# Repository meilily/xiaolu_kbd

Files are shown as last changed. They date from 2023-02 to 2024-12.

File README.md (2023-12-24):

Xiaolu Keyboard
===============

この Xiaolu Keyboard は、Seeed Xiao を使用した小型の自作キーボードです。このキーボードは、テンキーやゲーム用のマクロキーボードなどとして使用できる、コンパクトで手のひらサイズのデバイスとして設計されています。キーボードには、4×4グリッドに配置された合計16個の小さなキーが使用されています。

このキーボードを作るには、基本的なハンダ付けの技術と工具、そしてSeeed Xiao用にファームウェアをビルドしてインストールする必要があります。必要なものがすべて揃ったら、ビルドガイドを参照してください。

キーボードの組み立てに成功したら、ArduinoやQMKなどのファームウェアを使って、独自のマクロやカスタム機能でキーボードをプログラムすることができます。Arduinoのサンプルファームウェアでは、例としてシンプルな4x4のテンキー機能を提供しています。

## 特徴

* 秋月C基板互換サイズでコンパクトで手のひらサイズ (51mm x 76mm)
* Switronic TS-AGGNH-G プッシュボタンの採用により小型ながらもキースイッチの押しやすさを両立
* MCU として Seeed XIAO を採用

## 手順書

* [パーツリスト](docs/bom.md)
* [ビルドガイド](docs/building_instruction.md)
* [拡張機能](docs/extensible_features.md)

## 外観図

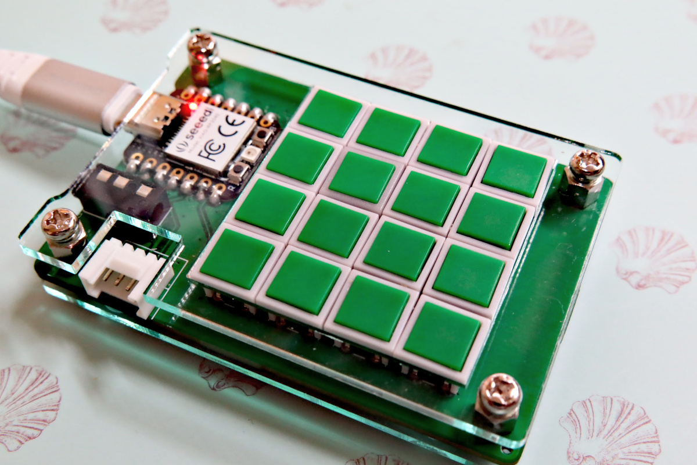
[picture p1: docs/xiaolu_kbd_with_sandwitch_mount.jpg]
組立例


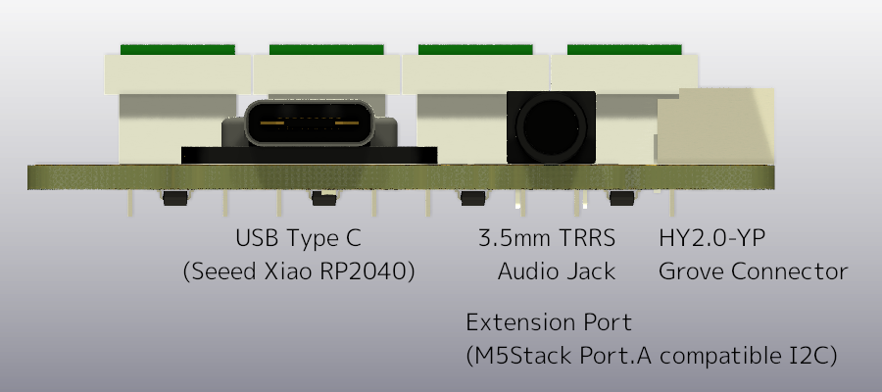
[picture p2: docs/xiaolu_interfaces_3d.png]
インタフェース(3D CG)


## License

licensed under the [CC-BY-SA-4.0](https://creativecommons.org/licenses/by-sa/4.0/) except for QMK.
QMK firmware source code is licensed under the [GPLv2](https://www.gnu.org/licenses/old-licenses/gpl-2.0.html)

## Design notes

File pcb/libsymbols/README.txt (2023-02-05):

Seeed_Studio_XIAO_Series.kicad_sym : https://github.com/Seeed-Studio/OPL_Kicad_Library/blob/master/Seeed%20Studio%20XIAO%20Series%20Library/Seeed_Studio_XIAO_Series.kicad_sym
keebio.lib : https://github.com/keebio/keebio-components/blob/master/keebio.lib

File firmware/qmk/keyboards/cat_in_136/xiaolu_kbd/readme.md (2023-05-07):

# Xiaolu KBD

cat\_in\_136/xiaolu\_kbd

*A short description of the keyboard/project*

* Keyboard Maintainer: [cat-in-136](https://github.com/cat-in-136)
* Hardware Supported: Xiaolu PCB, Seeed XIAO RP2040
* Hardware Availability: <https://github.com/cat-in-136/xiaolu_kbd>

Make example for this keyboard (after setting up your build environment):

    make cat_in_136/xiaolu_kbd:default

Flashing example for this keyboard:

    make cat_in_136/xiaolu_kbd:default:flash

See the [build environment setup](https://docs.qmk.fm/#/getting_started_build_tools) and the [make instructions](https://docs.qmk.fm/#/getting_started_make_guide) for more information. Brand new to QMK? Start with our [Complete Newbs Guide](https://docs.qmk.fm/#/newbs).

## Bootloader

Enter the bootloader in 3 ways:

* **Bootmagic reset**: Hold down the key at (0,0) in the matrix (usually the top left key or Escape) and plug in the keyboard
* **Physical reset button**: Briefly press the button on the back of the PCB - some may have pads you must short instead
* **Keycode in layout**: Press the key mapped to `QK_BOOT` if it is available

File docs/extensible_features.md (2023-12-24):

拡張機能
========

この Xiaolu Keyboard には、オプショナルなパーツとして Grove コネクタおよび TRRS ジャックをつけることができます。これらのインタフェースを介して他のユニットと接続し、ファームウェアを適切に実装することで、キーボードの機能を拡張することができます。

## 配線

Grove コネクタおよび TRRS ジャックは下記の通り接続されます。

|Seeed Xiao RP2040 Pin|Grove(M5Stack互換)|TRRS  |
|---|---|---|
|GND |1 (Black/GND) |Sleeve|
|5V |2 (Red/5V) |Tip |
|P6/SDA/D4 |3 (Yellow/SDA) |Ring2 |
|P7/SCL/D5 |4 (White/SCL) |Ring1 |



Grove コネクタと TRRS ジャックの電源供給は、どちらも 5V が供給されます。

I2C のプルアップは、3.3V に 4.7 kΩの抵抗を接続するのが標準です。
4.7 kΩの抵抗が PCB に実装されていますので、ハンダブリッジジャンパで有効にすることで、このプルアップすることができます。

I2C のプルアップ抵抗は、4.7 kΩが標準値ですが、必要に応じて変更してください。

## ファームウェア

### I2C -- Arduino/PlatformIO

RP2040 の標準の I2C 用途のピンを使っているので、ArduinoのWireライブラリの関数を使用して I2C デバイスにアクセスできます。
すなわち、 `Wire.begin()` 関数を使用して I2C バスを初期化し、 `Wire.write()` 関数を使用して I2C デバイスにデータを送信し、あるいは `Wire.read()` 関数を使用してデータを受信できます。

Wireライブラリの使い方の詳細については、[Arduino の Wireライブラリの公式ドキュメント](https://www.arduino.cc/reference/en/language/functions/communication/wire/)を参照してください。

```c++
#include <Wire.h>

void setup() {
  // ...
  Wire.begin();
  // ...
}

void loop() {
  Wire.requestFrom(device_address, 1);
  while (Wire.available()) {
    // Wire.read();
    // ...
  }
  // ...
}
```

### I2C -- QMK

QMKでI2Cを使用するには、以下の設定が必要です。

**rules.mk**: `QUANTUM_LIB_SRC` に `i2c_master.c` を追加します。

```make
QUANTUM_LIB_SRC += i2c_master.c
```

**halconf.h**: `HAL_USE_I2C` を `TRUE` に設定します。

```c++
#pragma once

#define HAL_USE_I2C TRUE

#include_next <halconf.h>
```

**mcuconf.h**: `RP_I2C_USE_I2C1` を `TRUE` に設定します。使わない `RP_I2C_USE_I2C0` は `FALSE` に設定します。

```c++
#pragma once

#include_next <mcuconf.h>

#undef RP_I2C_USE_I2C0
#undef RP_I2C_USE_I2C1
#define RP_I2C_USE_I2C0 FALSE
#define RP_I2C_USE_I2C1 TRUE
```

**config.h**: 以下の設定を追加します

* `I2C_DRIVER` は、I2Cドライバの種類として I2C1 を指定します。
* `I2C1_SCL_PIN` と `I2C1_SDA_PIN` は、I2C1のSCL/SDAピンを指定します。それぞれ `GP7`, `GP6` を指定します。

```c++
#pragma once

// I2C
#define I2C_DRIVER I2CD1
#define I2C1_SCL_PIN GP7
#define I2C1_SDA_PIN GP6
```

これらの設定を行った後、I2Cデバイスを操作できるようになります。

**keymap.c**: 例えば下記のようにして I2C デバイスを制御します。

* `keyboard_post_init_user()` で `i2c_init()` を呼ぶことで I2C ドライバを初期化します。
* `matrix_scan_user()` で I2C デバイスの処理を行います。
* [QMKのI2CドライバのAPI](https://github.com/qmk/qmk_firmware/blob/master/docs/i2c_driver.md#api-idapi)関数群を使って I2C デバイスと通信を行います。

```c++
static void handle_i2c_device(void) {
    static const uint16_t TIMEOUT = 100;

    uint8_t c[1] = {0};
    const i2c_status_t error = i2c_receive(I2C_DEVICE_ADDR << 1, c, sizeof(c), TIMEOUT);
    if (error != I2C_STATUS_SUCCESS) {
        return; // quit on failure
    }

    // ...
}

void matrix_scan_user(void) {
    // ...
    handle_i2c_device();
}

void keyboard_post_init_user(void) {
    // ...
    i2c_init();
}
```

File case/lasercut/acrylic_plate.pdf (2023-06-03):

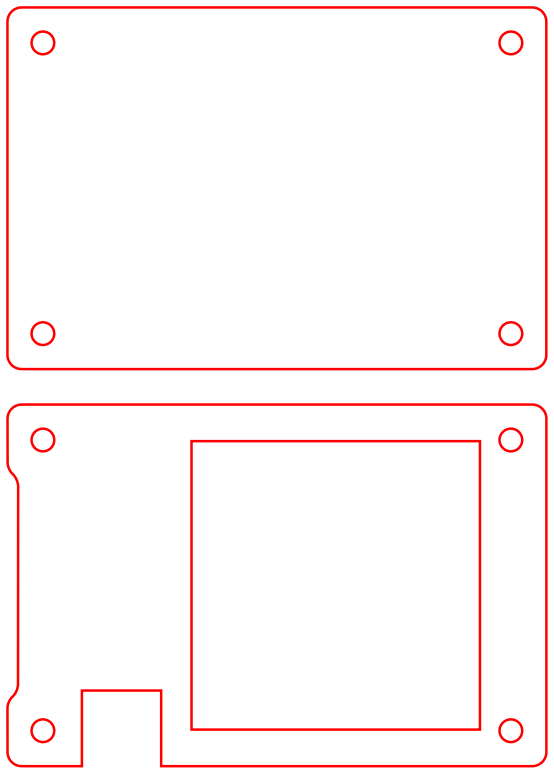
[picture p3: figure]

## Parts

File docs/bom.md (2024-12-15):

パーツリスト
============

## PCB

Xiaolu Keyboard PCBはKicad 6で設計され、51mm x 76mmの寸法を持つ2層設計になっています。PCBには、16個のダイオード（1N4148）と2個の4.7kΩ抵抗（4.7kΩ 0402 Resister）のSMT部品が含まれています。

.kicad_pcb、.kicad_schなどのPCB設計ファイルは、「pcb」フォルダーにあります。

このPCBは、一般的なPCBメーカーである[JLCPCB](https://jlcpcb.com/)で製造することを前提に設計されています。PCBをJLCPCB PCB+SMT製造サービスに発注するには、KiCadのプラグインで製造用のガーバーファイルなどのファブリケーションファイルを生成できる[JLCPCB fabrication toolkit](https://github.com/bennymeg/JLC-Plugin-for-KiCad)を利用することができます。このツールキットを使うと、JLCPCBに発注するのに必要なファブリケーションファイルであるgerber.zip、bom.csv、position.csvを生成できます。

SMT 部品表

|部品名 |数量|LCSC Part # |
|---|----|---|
|1N4148 Diode |16  |[C2128](https://www.lcsc.com/product-detail/Switching-Diode_Jiangsu-Changjing-Electronics-Technology-Co-Ltd-1N4148WS_C2128.html)|
|4.7kΩ 0402 Resistor|2 |[C25900](https://www.lcsc.com/product-detail/Chip-Resistor-Surface-Mount_UNI-ROYAL-Uniroyal-Elec-0402WGF4701TCE_C25900.html) |

## 電子部品

|部品名 |数量|秋月通販コード |備考 |
|---|----|---|---|
|Seeed XIAO RP2040 |1 |[117044](https://akizukidenshi.com/catalog/g/g117044/)|必須 |
|Switronic TS-AGGNH-G プッシュボタン |16  |[103654](https://akizukidenshi.com/catalog/g/g103654/)|必須 |
|USB Type C ケーブル |1 | |必須。適当なもので良い |
|GroveコネクタL型スルーホール |1 |[112634](https://akizukidenshi.com/catalog/g/g112634/)|Grove拡張用オプション部品|
|TRRS ジャック PJ-320A(または MJ-4PP-9)|1 |[106070](https://akizukidenshi.com/catalog/g/g106070/)|TRRS拡張用オプション部品 |

## ケース

ケースセットアップの例をいくつか記載します。

### 最も安価なケースセットアップ〜市販品の利用〜

Xiaolu Keyboard PCBは、ケースの組み立てを容易にするために、四隅にM3ホールが配置されています。このM3ホールは、秋月電子のC基板との互換となる配置と直径になっています。これにより、秋月電子C基板用のケースやアクリルパネルに、Xiaolu Keyboard を簡単に組み込むことができます。

以下は、最も安価なケースセットアップの一例です。より高さを低くするにはより短いスペーサーを使用してください。

|部品名 |数量|秋月通販コード |備考 |
|---|----|---|---|
|C基板用アクリルパネル |1 |[109853](https://akizukidenshi.com/catalog/g/g109853/)| |
|3mmプラネジ(7mm)+六角スペーサー(14mm)セット|1 |[101861](https://akizukidenshi.com/catalog/g/g101861/)|8 x M3プラネジと4 x M3スペーサーのセット|

### サンドイッチマウントケース

カードケース（名刺ケース）に入るよう設計されたサンドイッチマウントケースです。

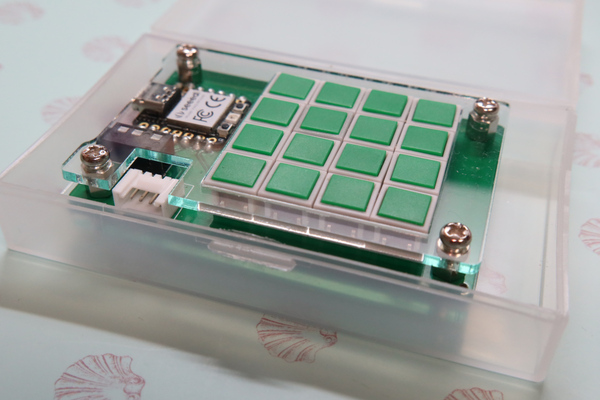
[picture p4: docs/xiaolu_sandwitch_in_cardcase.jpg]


アクリル板のデザインは [case/lasercut/acrylic_plate.pdf](../case/lasercut/acrylic_plate.pdf) にあります。
お手持ちのレーザー加工機もしくはレーザー加工サービスの入稿条件に従って編集しボトムプレートとトッププレートを製造してください。

|部品名 |数量|通販 |備考 |
|---|----|---|---|
|ボトムプレート (76mm x 51mm x 2mm)|1 | |※レーザー加工によって製造 |
|トッププレート (76mm x 51mm x 2mm)|1 | |※レーザー加工によって製造 |
|なべ小ねじ M3 x 4mm |4 |[千石電商: EEHD-6DKV](https://www.sengoku.co.jp/mod/sgk_cart/detail.php?code=EEHD-6DKV)| |
|なべ小ねじ M3 x 8mm |4 |[千石電商: EEHD-6DKY](https://www.sengoku.co.jp/mod/sgk_cart/detail.php?code=EEHD-6DKY)| |
|六角ナット M3 x 2.4mm |4 |[千石電商: EEHD-6EBP](https://www.sengoku.co.jp/mod/sgk_cart/detail.php?code=EEHD-6EBP)|スペーサの代わりに使用。JIS B1181 規格の六角ナット|
|六角スペーサ 両メネジ M3 x 5mm |4 |[千石電商: EEHD-0DLK](https://www.sengoku.co.jp/mod/sgk_cart/detail.php?code=EEHD-0DLK)| |

## 工具

Xiaolu Keyboard PCBはハンダ付けが必要なため、ハンダ付けやその他の電子工作のための一般的な工具が必要です。

* ハンダごて - 温度調節機能付きのものでも、ベーシックなものでもよいのですが、温度調節機能付きのものを強くお勧めします。
* ハンダ - この組み立てには、はんだが必要です。
* ドライバーセット - ケースの組み立てには、ドライバーセットが必要です。

工具を扱うときは、常に適切な安全対策に従ってください。

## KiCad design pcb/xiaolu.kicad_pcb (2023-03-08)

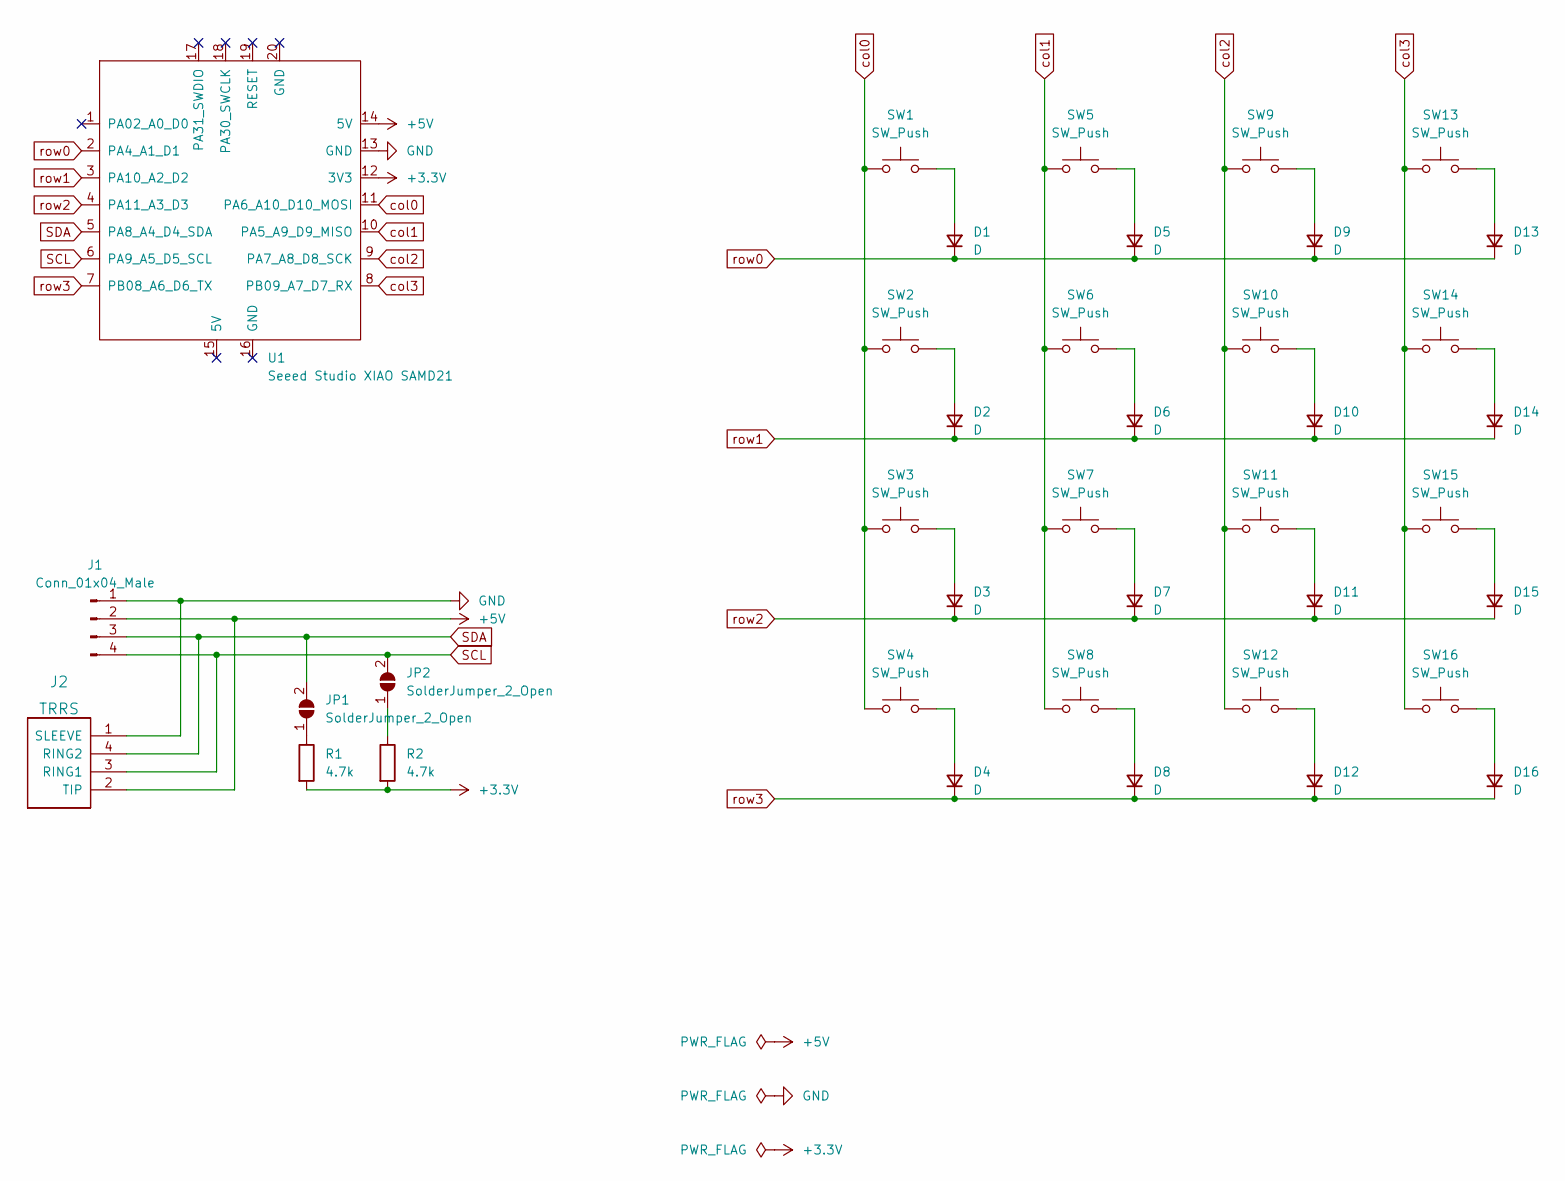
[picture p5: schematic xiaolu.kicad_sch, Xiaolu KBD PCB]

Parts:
D1, D2, D3, D4, D5, D6, D7, D8, D9, D10, D11, D12, D13, D14, D15, D16: D; D_SOD-323; LCSC Part # C2128
J1: Conn_01x04_Male; NS-Tech_Grove_1x04_P2mm_Hybrid
J2: TRRS; TRRS-PJ-320A
JP1, JP2: SolderJumper_2_Open; SolderJumper-2_P1.3mm_Open_RoundedPad1.0x1.5mm
R1, R2: 4.7k; R_0402_1005Metric; LCSC Part # C25900
SW1, SW2, SW3, SW4, SW5, SW6, SW7, SW8, SW9, SW10, SW11, SW12, SW13, SW14, SW15, SW16: SW_Push; SW_PUSH_Switronic_TS-AXXXH
U1: Seeed Studio XIAO SAMD21; XIAO-Generic-Hybrid-14P-2.54-21X17.8MM

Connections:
+3.3V: R1.2, R2.2, U1.12 (3V3)
+5V: J1.2, J2.2 (TIP), U1.14 (5V)
GND: J1.1, J2.1 (SLEEVE), U1.13 (GND)
unnamed: D1.2 (A), SW1.2
unnamed: D2.2 (A), SW2.2
unnamed: D3.2 (A), SW3.2
unnamed: D4.2 (A), SW4.2
unnamed: D5.2 (A), SW5.2
unnamed: D6.2 (A), SW6.2
unnamed: D7.2 (A), SW7.2
unnamed: D8.2 (A), SW8.2
unnamed: D9.2 (A), SW9.2
unnamed: D10.2 (A), SW10.2
unnamed: D11.2 (A), SW11.2
unnamed: D12.2 (A), SW12.2
unnamed: D13.2 (A), SW13.2
unnamed: D14.2 (A), SW14.2
unnamed: D15.2 (A), SW15.2
unnamed: D16.2 (A), SW16.2
unnamed: JP1.1 (A), R1.1
unnamed: JP2.1 (A), R2.1
SCL: J1.4, J2.3 (RING1), JP2.2 (B), U1.6 (PA9_A5_D5_SCL)
SDA: J1.3, J2.4 (RING2), JP1.2 (B), U1.5 (PA8_A4_D4_SDA)
col0: SW1.1, SW2.1, SW3.1, SW4.1, U1.11 (PA6_A10_D10_MOSI)
col1: SW5.1, SW6.1, SW7.1, SW8.1, U1.10 (PA5_A9_D9_MISO)
col2: SW9.1, SW10.1, SW11.1, SW12.1, U1.9 (PA7_A8_D8_SCK)
col3: SW13.1, SW14.1, SW15.1, SW16.1, U1.8 (PB09_A7_D7_RX)
row0: D1.1 (K), D5.1 (K), D9.1 (K), D13.1 (K), U1.2 (PA4_A1_D1)
row1: D2.1 (K), D6.1 (K), D10.1 (K), D14.1 (K), U1.3 (PA10_A2_D2)
row2: D3.1 (K), D7.1 (K), D11.1 (K), D15.1 (K), U1.4 (PA11_A3_D3)
row3: D4.1 (K), D8.1 (K), D12.1 (K), D16.1 (K), U1.7 (PB08_A6_D6_TX)

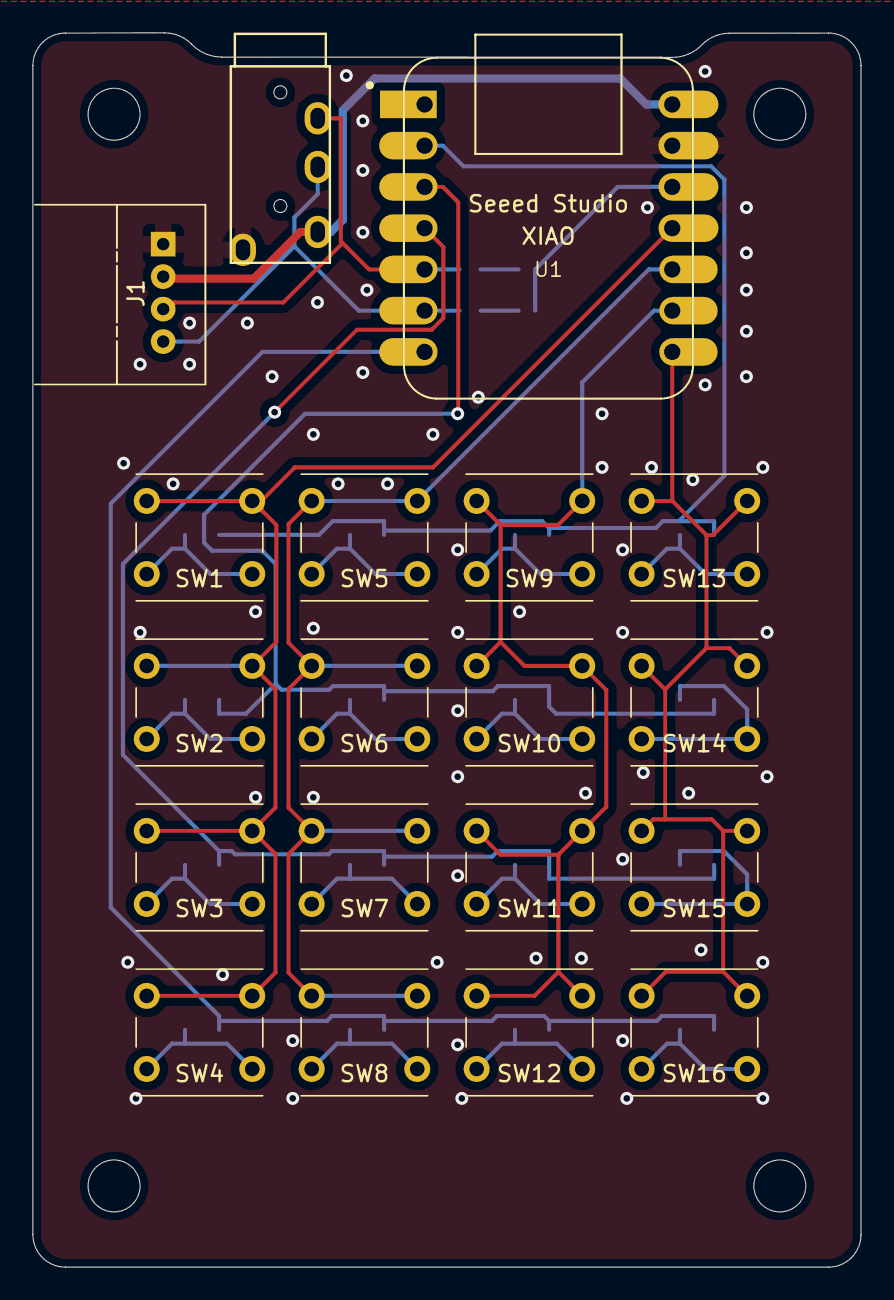
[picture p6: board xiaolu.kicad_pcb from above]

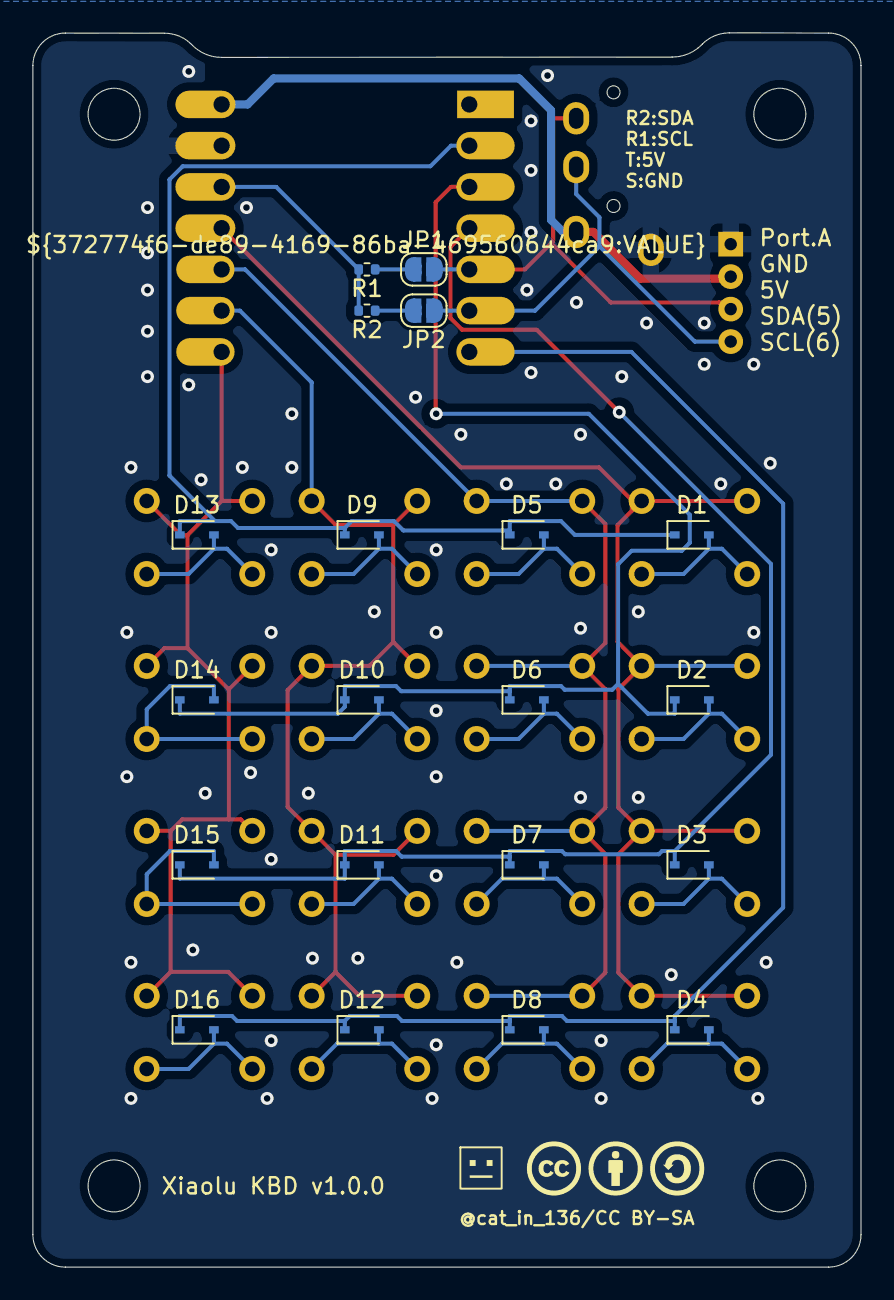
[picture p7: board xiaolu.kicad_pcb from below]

Board: 2 copper layers, 51.0 x 76.0 mm, 39 parts (20 on the bottom side), 31 nets.

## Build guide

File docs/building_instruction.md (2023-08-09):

ビルドガイド
============

## PCB 実装

### ステップ 0

ダイオードや抵抗がPCB+SMT製造サービスによって既に実装されている場合は、このステップをスキップしてください。

* 16 x 1N4148 Diodes (D1-D16)
* 2 x 4.7kΩ 0402 Resistor (R1, R2)

これらのダイオードは方向性があります。カソードが左、アノードが右です。

### ステップ 1

* Seeed Xiao RP2040 (U1)

PCB上にSeeed Xiaoボードを置き、Seeed Xiaoの端面スルーホールととPCB上の対応するパッドが以下の3D CGのように一致するようにします。

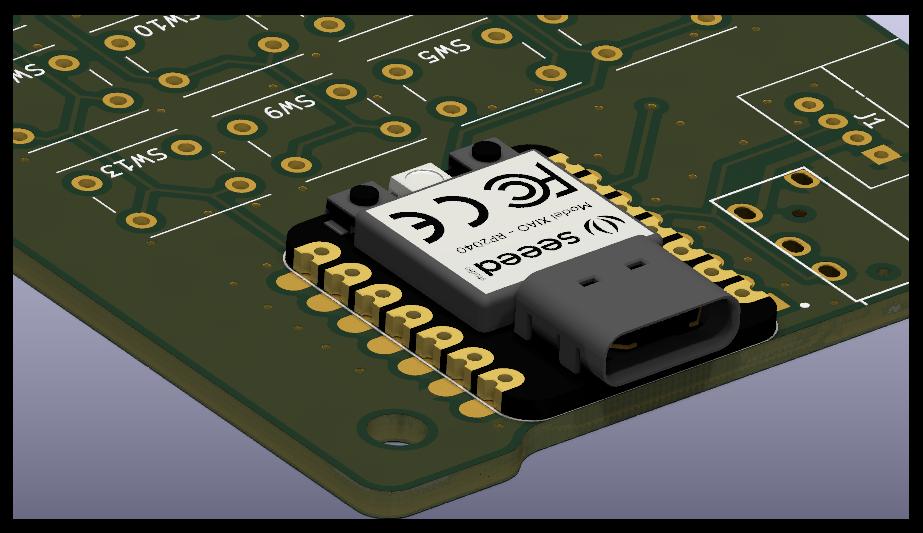
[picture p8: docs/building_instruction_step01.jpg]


それぞれの端面スルーホールをとパッドをはんだ付けします。

補足：また、プリント基板にはスルーホールが設けられています。これは位置合わせのために使うこともできますし、強度を増すなどの理由があればスルーホールをハンダ付けすることも可能です。

### ステップ 2

* 1 x TRRS ジャック PJ-320A(または MJ-4PP-9) (TRRS)

TRRS拡張用オプション部品です。不要な場合はこのステップをスキップしてください。

TRRSジャックをPCBに挿入してテープで固定します。フットプリントがぴったり合うように作られているので、きちんと押し込んでください。PCBを裏返します。ピンをはんだ付けします。テープを剥がします。

### ステップ 3

* 1 x GroveコネクタL型スルーホール (J1)

Grove拡張用オプション部品です。不要な場合はこのステップをスキップしてください。

GroveコネクタをPCBに挿入してテープで固定します。PCBを裏返します。ピンをはんだ付けします。テープを剥がします。

### ステップ 4

* 16 x Switronic TS-AGGNH-G プッシュボタン (SW1-16)

プッシュボタンをPCBに挿入してテープで固定します。

スルーホールにうまく入らない場合は、プッシュボタンの足をペンチなどでまっすぐにして入りやすくしてください。
下図の左がペンチでまっすぐにした後の足です。

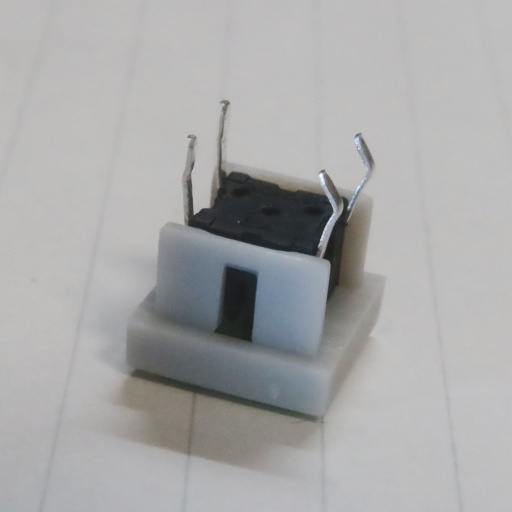
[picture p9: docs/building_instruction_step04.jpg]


PCBを裏返します。ピンをはんだ付けします。テープを剥がします。

## ケース

### 最も安価なケースセットアップ〜市販品の利用〜

下図のようにして、アクリルパネルをスペーサーとプラネジで固定します。

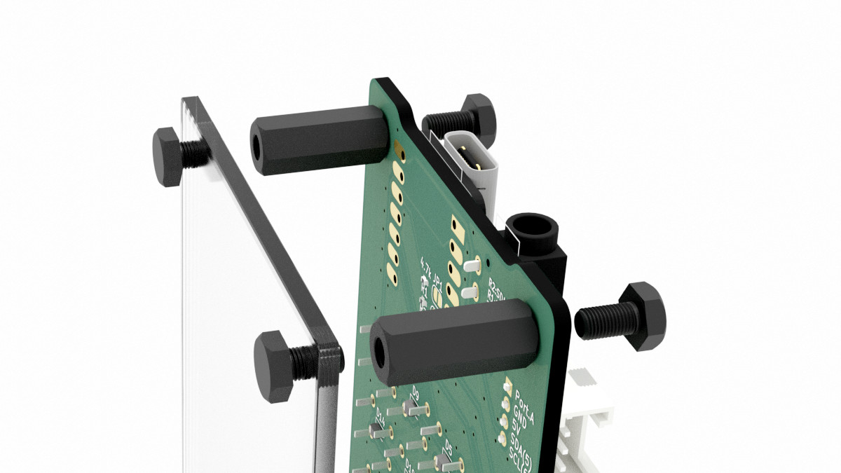
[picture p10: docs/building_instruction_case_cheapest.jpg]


### サンドイッチマウントケース

PCB背面に出ているプッシュボタン Switronic TS-AGGNH-G プッシュボタン (SW1-16) および GroveコネクタL型スルーホール (J1) の足が 2mm 以上出ている場合はニッパーなどで切りそろえます。

なべ小ねじ M3 x 8mm → ボトムプレート → 六角ナット M3 x 2.4mm → PCB → 六角スペーサ → トッププレート → なべ小ねじ M3 x 4mm の順番に重ねます。
両端のねじをドライバーなどでしっかりと締めて固定します。

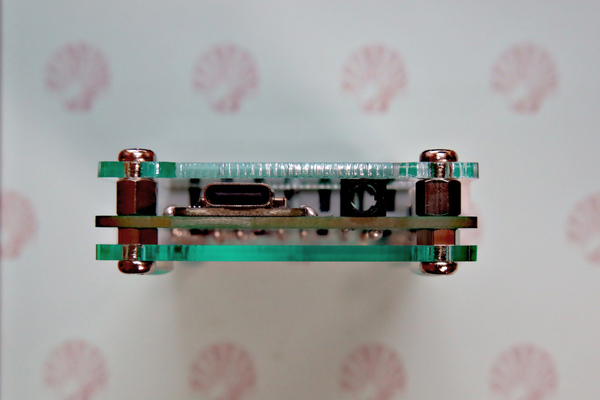
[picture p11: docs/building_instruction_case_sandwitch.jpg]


TRRSジャックを付けている場合にはTRRSジャックもトッププレートが支える実装となります。

## ファームウェア

サンプルファームウエアは Platform IO (Arduino) と QMK を用意しています。

### Platform IO/Arduino

サンプルファームウェアの Platform IO プロジェクトは [/firmware/platformio_arduino](../firmware/platformio_arduino) にあります。

必要に応じてプログラムを追加・編集してください。
[サンプルファームウエアのコード](../firmware/platformio_arduino/src/main.c) はシンプルなテンキーで、
さらにGroveコネクタに[M5stack CardKB Unit](https://docs.m5stack.com/en/unit/cardkb_1.1)をつないだときCardKB Unitの入力をキーボード入力に変換する処理が含まれます。

以下に Windows + Visual Studio Code 環境でのファームウェアのビルド・アップロードの方法を記載します。

1. <https://zadig.akeo.ie/> から Zadig をダウンロードします
2. Zadig を起動します
3. PC の USB に Xiaolu KBD をつなぎます
4. Seeed Xiao RP2040 の BOOTボタンを押した状態でリセットボタンを押します。すると、USBマスストレージモード(RPI-RP2)でつながります
5. すると Zadig のウィンドウで RP2 Boot (Interface X) が選択されます。選択されない場合はセレクトボックスから選択します
6. インストール先のドライバとして WinUSB を選択して、 Install Driver ボタンをクリックします
7. しばらくすると The driver was installed successfuly というダイアログが表示されドライバがインストールされます。これで Zadig のウィンドウを閉じます
8. <https://github.com/git-for-windows/git/releases/latest> から Git for Windows をダウンロード・インストールします
9. 後述の手順16でファイルパスが長いことに起因するエラーを防ぐため、以下の手順でロングパス対応します
    1. レジストリエディタを開きます
    2. `コンピューター\HKEY_LOCAL_MACHINE\SYSTEM\CurrentControlSet\Control\FileSystem` に移動します
    3. `LongPathsEnabled` というDWORDの値があることを確認します。ない場合は作成します
    4. `LongPathsEnabled` の値を `1` に設定します
    5. コマンドプロンプトを開き、`git config --system core.longpaths true` と入力して実行します
    6. Windows を再起動します
10. <https://code.visualstudio.com/> から Visual Studio Code をダウンロード・インストールします
11. Visual Studio Code を起動して [PlatformIO IDE](https://marketplace.visualstudio.com/items?itemName=platformio.platformio-ide) 拡張をインストールします。（ VS Code Quick Open (Ctrl+P) で表示されるテキストボックスに `ext install platformio.platformio-ide` を入力して Enter でインストール出来ます ）
12. PlatformIO IDE has been installed successfully installed! Please reload windows と表示されるので Reload Now と書かれたボタンをクリックします
13. <https://github.com/cat-in-136/xiaolu_kbd> を Git で適当なフォルダにクローンするか、 <https://codeload.github.com/cat-in-136/xiaolu_kbd/zip/refs/heads/main> からダウンロードして適当なフォルダに展開します
14. Visual Studio Code の Platformio をクリックして、Pick a folder をクリックし、前項で展開したフォルダの中の [firmware\\platformio_arduino](../firmware/platformio_arduino) 相当のフォルダを選択します
15. "Do you trust the authors of the files in this folder?" というダイアログが出たら "Yes, I trust the authors" と書かれたボタンをクリックします
16. すると依存ライブラリのダウンロードなど (PlatformIO: Configuring project) がされますのでしばらく待ちます
17. Visual Studio Code の下の [PlatformIO Toolbar](https://docs.platformio.org/en/latest/integration/ide/vscode.html#ide-vscode-toolbar) から → Upload をクリックします
    * 手順 17 でファームウェアのアップロードに失敗するときは、USB がきちんとささっていない他に、 WinUSB がインストールされていない場合があります。

### QMK

[/firmware/qmk/keyboards/cat_in_136/xiaolu_kbd](../firmware/qmk/keyboards/cat_in_136/xiaolu_kbd) を `keyboards/cat_in_136/xiaolu_kbd` にコピーして QMK をビルド・アップロードします。

必要に応じてキーマップを追加・編集してください。
デフォルトキーマップはシンプルなテンキーになっています。

以下に Windows + QMK MSYS 環境でのファームウェアのビルド・アップロードの方法を記載します。

1. <https://msys.qmk.fm/> から QMK MSYS をダウンロード・インストールします
2. QMK MSYS を起動します。
3. コンソール画面で下記を実行します。
   ```console
   $ qmk setup
   ```
4. <https://github.com/cat-in-136/xiaolu_kbd> を Git で適当なフォルダにクローンするか、 <https://codeload.github.com/cat-in-136/xiaolu_kbd/zip/refs/heads/main> からダウンロードして適当なフォルダに展開します
5. 前項で展開したフォルダから `firmware/qmk` を `qmk_firmware/keyboards/cat_in_136/xiaolu_kbd` にコピーします。
   ```console
   $ mkdir qmk_firmware/keyboards/cat_in_136
   $ cp -r path/to/xiaolu_kbd/firmware/qmk/keyboards/cat_in_136/xiaolu_kbd qmk_firmware/keyboards/cat_in_136/xiaolu_kbd
   ```
6. qmk をコンパイルします。
   ```console
   $ qmk compile -kb cat_in_136/xiaolu_kbd -km default
   $ qmk flash -kb cat_in_136/xiaolu_kbd -km default
   ```
7. qmk をアップロードします。
   ```console
   $ qmk flash -kb cat_in_136/xiaolu_kbd -km default
   ```
8. 途中で Waiting for drive to deploy... と表示されるので、Seeed Xiao RP2040 の BOOTボタンを押した状態でリセットボタンを押します。するとファームウエアの書き込みが完了します。
9. Xiaolu KBD がキーボードとして認識されるまでしばらく待ちます。

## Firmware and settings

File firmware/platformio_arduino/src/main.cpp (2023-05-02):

#include <Adafruit_Keypad.h>
#include <Adafruit_NeoPixel.h>
#include <Arduino.h>
#include <Keyboard.h>
#include <Wire.h>

/// Row count of the key matrix
static const byte KEY_ROWS = 4;

/// Column count of the key matrix
static const byte KEY_COLS = 4;

/// Row pins (OUT) of the key matrix
static const byte KEY_ROWPINS[KEY_ROWS] = {
    // D1, D2, D3, D6
    27, 28, 29, 0};

/// Column pins (IN) of the key matrix
static const byte KEY_COLPINS[KEY_COLS] = {
    // D10, D9, D8, D7
    3, 4, 2, 1};

/// Definition of the symbol for each key
///
/// @attention
/// Xiaolu is different from the input/output pin layout assumed by
/// Adafruit_Keypad, so symbol is specified in an inverted matrix.
static const char KEY_SYMBOL[KEY_COLS][KEY_ROWS] = {{'7', '4', '1', '0'},
                                                    {'8', '5', '2', '.'},
                                                    {'9', '6', '3', '\n'},
                                                    {'/', '*', '-', '+'}};

/// Key matrix
Adafruit_Keypad keymatrix(makeKeymap(KEY_SYMBOL),
                          const_cast<byte *>(KEY_COLPINS),
                          const_cast<byte *>(KEY_ROWPINS), KEY_COLS, KEY_ROWS);

/// I2C address of M5Stack CardKB
static const uint8_t CARKB_ADDR = 0x5F;

/// Symbol Key Mapping for M5Stack CardKB
static const uint8_t CARKB_KEYMAP[][3] = {
    {0x08, KEY_BACKSPACE, 0},
    {0x09, KEY_TAB, 0},
    {0x0D, KEY_RETURN, 0},
    {0x1B, KEY_ESC, 0},
    {0xb5, KEY_UP_ARROW, 0},
    {0xb6, KEY_DOWN_ARROW, 0},
    {0xb4, KEY_LEFT_ARROW, 0},
    {0xb7, KEY_RIGHT_ARROW, 0},
    // Shift + Key combination
    {0x7f, KEY_DELETE, 0}, // Shift + Backspace
    // Fn + Key combination
    {0x81, KEY_F1, 0},           // Fn + 1
    {0x82, KEY_F2, 0},           // Fn + 2
    {0x83, KEY_F3, 0},           // Fn + 3
    {0x84, KEY_F4, 0},           // Fn + 4
    {0x85, KEY_F5, 0},           // Fn + 5
    {0x86, KEY_F6, 0},           // Fn + 6
    {0x87, KEY_F7, 0},           // Fn + 7
    {0x88, KEY_F8, 0},           // Fn + 8
    {0x89, KEY_F9, 0},           // Fn + 9
    {0x8a, KEY_F10, 0},          // Fn + 0
    {0x8b, KEY_F11, 0},          // Fn + Backspace
    {0x99, KEY_PAGE_UP, 0},      // Fn + Up
    {0xa4, KEY_PAGE_DOWN, 0},    // Fn + Down
    {0x98, KEY_HOME, 0},         // Fn + Left
    {0xa5, KEY_END, 0},          // Fn + Right
    {0x96, KEY_PRINT_SCREEN, 0}, // Fn + P
    {0xa6, 'z', KEY_LEFT_CTRL},  // Fn + Z
    {0xa7, 'x', KEY_LEFT_CTRL},  // Fn + X
    {0xa8, 'c', KEY_LEFT_CTRL},  // Fn + C
    {0xa9, 'v', KEY_LEFT_CTRL},  // Fn + V
    {0xaa, KEY_PAUSE, 0},        // Fn + B
    {0xab, KEY_NUM_LOCK, 0},     // Fn + N
    {0xac, KEY_MENU, 0},         // Fn + M
    {0xaf, ' ', KEY_LEFT_CTRL},  // Fn + SPACE
};

/// LED length of the NeoPixel LED
static const uint16_t NEO_NUMPIXELS = 1;

/// Power pin of NeoPixel LED
static const pin_size_t NEO_PWR = 11; // GPIO11

/// Pixel data pin of NeoPixel LED
static const pin_size_t NEO_PIX = 12; // GPIO12

/// NeoPixel LED
Adafruit_NeoPixel pixels(NEO_NUMPIXELS, NEO_PIX, NEO_GRB + NEO_KHZ800);

/// Arduino setup entry point (Core 0)
void setup() {
  pixels.begin();
  pinMode(NEO_PWR, OUTPUT);
  digitalWrite(NEO_PWR, HIGH);

  pixels.setBrightness(25);
  pixels.setPixelColor(0, pixels.Color(255, 255, 255));
  pixels.show();

  Serial.begin(115200);
  // while (!Serial) { delay(1); }
  delay(100);
  Serial.println("Boot Xiaolu KBD Arduino FW ...");

  keymatrix.begin();

  Keyboard.begin();

  Wire.begin();

  delay(2000);

  pixels.setPixelColor(0, pixels.Color(0, 0, 0));
  pixels.show();

  Serial.println("Ready.");
}

/// Arduino loop function (Core 0)
void loop() {
  uint8_t key_count = 0;

  keymatrix.tick();

  while (keymatrix.available()) {
    const keypadEvent e = keymatrix.read();
    const char key = (char)e.bit.KEY;

    Serial.print((key == '\n') ? "ENTER" : String(key));
    if (e.bit.EVENT == KEY_JUST_PRESSED) {
      Serial.println(" pressed.");
    } else if (e.bit.EVENT == KEY_JUST_RELEASED) {
      Serial.println(" released");
    }
    Serial.flush();

    uint8_t key_code = 0;
    if (key == '0') {
      key_code = KEY_KP_0;
    } else if (isDigit(key)) {
      key_code = KEY_KP_1 + (key - KEY_KP_1);
    } else if (key == '.') {
      key_code = KEY_KP_DOT;
    } else if (key == '/') {
      key_code = KEY_KP_SLASH;
    } else if (key == '*') {
      key_code = KEY_KP_ASTERISK;
    } else if (key == '-') {
      key_code = KEY_KP_MINUS;
    } else if (key == '+') {
      key_code = KEY_KP_PLUS;
    } else if (key == '\n') {
      key_code = KEY_KP_ENTER;
    }

    if ((key_code != 0) && (e.bit.EVENT == KEY_JUST_PRESSED)) {
      Keyboard.press(key_code);
    } else if ((key_code != 0) && (e.bit.EVENT == KEY_JUST_RELEASED)) {
      Keyboard.release(key_code);
    }
  }

  Wire.requestFrom(CARKB_ADDR, 1);
  while (Wire.available()) {
    const char c = Wire.read();
    if (c != 0) {
      if (isPrintable(c)) {
        Serial.printf("%02x \"%c\" received from CardKB\n", c, c);
        Keyboard.write(c);
      } else {
        Serial.printf("%02x received from CardKB\n", c);

        uint8_t key_code = 0;
        uint8_t modifier_key_code = 0;
        for (const auto keymap : CARKB_KEYMAP) {
          if (c == keymap[0]) {
            key_code = keymap[1];
            modifier_key_code = keymap[2];
            break;
          }
        }

        if (key_code != 0) {
          if (modifier_key_code != 0) {
            Keyboard.press(modifier_key_code);
            delay(10);
          }
          Keyboard.press(key_code);
          delay(10);
          Keyboard.releaseAll();
        }
      }
    }
  }

  delay(10);
}

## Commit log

2023-02-02 introduce pcb directory (with empty pcb design)
    [xiaolu.kicad_pcb, xiaolu.kicad_sch]
2023-02-05 draft schematic and board design
    [Grove_Connector.scad, PJ-320A.step, TS-AGGNH-G.scad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]
2023-02-05 fix TRRS symbol
    [xiaolu.kicad_pcb, xiaolu.kicad_sch]
2023-02-08 replace XIAO footprint with XIAO-Generic-Hybrid-14P-2.54-21X17.8MM
    [xiaolu.kicad_pcb, xiaolu.kicad_sch]
2023-02-17 add notch for XIAO-usb and TRRS-jack to the PCB board edge
    [xiaolu.kicad_pcb]
2023-02-18 put each silk label on its internal
    [xiaolu.kicad_pcb]
2023-02-18 add slikscreen logos and label
    [xiaolu.kicad_pcb]
2023-02-18 fix Grove connector
    [xiaolu.kicad_pcb, xiaolu.kicad_sch]
2023-02-18 add I2C pin layout label
    [xiaolu.kicad_pcb]
2023-02-19 use NS-Tech_Grove_1x04_P2mm_Hybrid.kicad_mod for grove connector footprint and fix the Grove connector position
    [xiaolu.kicad_pcb, xiaolu.kicad_sch]
2023-02-19 fix SDA/SCL pin numbers of I2C pin layout label
    [xiaolu.kicad_pcb]
2023-02-21 Assign "LCSC Part #" of diodes (D1....D16) to C2128 (1N4148WS)
    [xiaolu.kicad_pcb, xiaolu.kicad_sch]
2023-02-24 add 3d model of XIAO RP2040
    [xiaolu.kicad_pcb]
2023-02-24 add pcb/libfootprints.pretty/3dmodels/README.txt
2023-03-06 flag unconnected to unused pads of xiao
    [xiaolu.kicad_sch]
2023-03-06 fix "LCSC Part #"
    [xiaolu.kicad_pcb, xiaolu.kicad_sch]
2023-03-06 add optional pull-up registers to I2C SDA/SCL
    [xiaolu.kicad_pcb, xiaolu.kicad_sch]
2023-03-06 modify fill ground, its vias
    [xiaolu.kicad_pcb]
2023-03-08 fix silk and GND vias
    [xiaolu.kicad_pcb]
2023-03-08 PCB version 1.0.0
    [xiaolu.kicad_pcb, xiaolu.kicad_sch]
2023-05-01 sample firmware of platfomio/arduino (maxgerhardt/platform-raspberrypi)
2023-05-02 support M5Stack CardKB Unit on platform_io arduino example FW
2023-05-02 add DEL key map of m5stack CardKB Unit on platform_io arduino example FW
2023-06-03 add lasercut case design
2023-06-12 sandwitch mount cheap case
2023-06-14 add sandwitch mount case to document
2023-06-17 add Platform IO/Arduino FW build guide
2023-08-08 ファームウェアのアップロードに失敗する問題を修正
2023-08-09 Platform IO/Arduino手順に Git for Windows のインストールを追記
2023-08-09 ロングパス対応を手順中の注意書きから前段に移動
2023-12-24 add doc/extensible_features.md (拡張機能)
2023-12-24 Update README.md to add 特徴
2024-12-15 update bom.md of online shopping link
    - 秋月電子通商リンク更新
    - ネジ類に千石電商リンク追加

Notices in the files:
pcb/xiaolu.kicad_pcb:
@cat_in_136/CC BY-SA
